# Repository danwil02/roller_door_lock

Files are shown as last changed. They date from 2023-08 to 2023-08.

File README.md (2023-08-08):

# Roller Door Lock

Simple project to control a 3D printed locking mechanism for a garage roller door.

The final setup allows me to lock and unlock my old and un-motorised garage door remotely via HomeKit.

## Setup

Create a copy of `conf.json` called `conf.local.json`. Fill in your Wifi and MQTT broker details.

## Dependancies
- I used [mosquitto broker](https://mosquitto.org/) in this project.
- For homekit integration install [homebridge](https://homebridge.io/how-to-install-homebridge) and the [homebridge-mqtt](https://github.com/cflurin/homebridge-mqtt#readme) plugin.

## Hardware

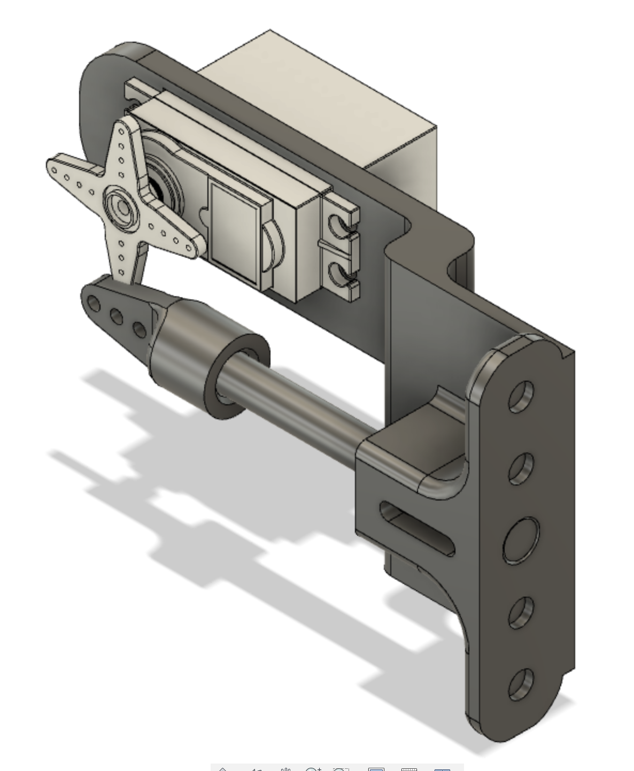
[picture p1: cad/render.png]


### 3D Printing
The following items were printed in PLA 0.4mm nozzle on a Prusa i3 mk3:
- `cad/bolt guide v3.stl`
- `cad/bolt control horn v1.stl`

### Assembly Notes
The bolt was a shortened 8mm OD smooth steel rod from an old Prusa printer left over from a previous upgrade. NOTE: Make sure to measure your setup to get an appropriate length.

The control horn attaches to the rod using glue and the horn attaches to the servo using chicken wire.

Finally, the assembly attaches to my garage door using two sheet metal screws.

For detailed informaiton see `cad/garage door lock assembly v4.step`.

### Essential Electronics
- Raspberry Pi Pico W with Soldered Male Headers
- Raspberry Pi 4 Power Supply (Official) - USB-C 5.1V 15.3W (White)	1
- PiicoDev Precision Temperature Sensor TMP117
- PiicoDev Cable 50mm	x4
- PiicoDev Cable 100mm	x5
- PiicoDev OLED Display Module (128x64) SSD1306
- PiicoDev Buzzer Module
- PiicoDev Expansion Board for Pico (Non-Recharging)
- PiicoDev Servo Driver (4 Channel)

### Optional Electronics
Could be used to extend the project in the future.
- USB Cable Type A to Micro B (1m)	x4
- Heat Shrink Kit
- 16mm Illuminated Pushbutton - Red Latching On/Off Switch	x2
- Resistor 330 Ohm 1/4 Watt PTH - 20 pack (Thick Leads)	1

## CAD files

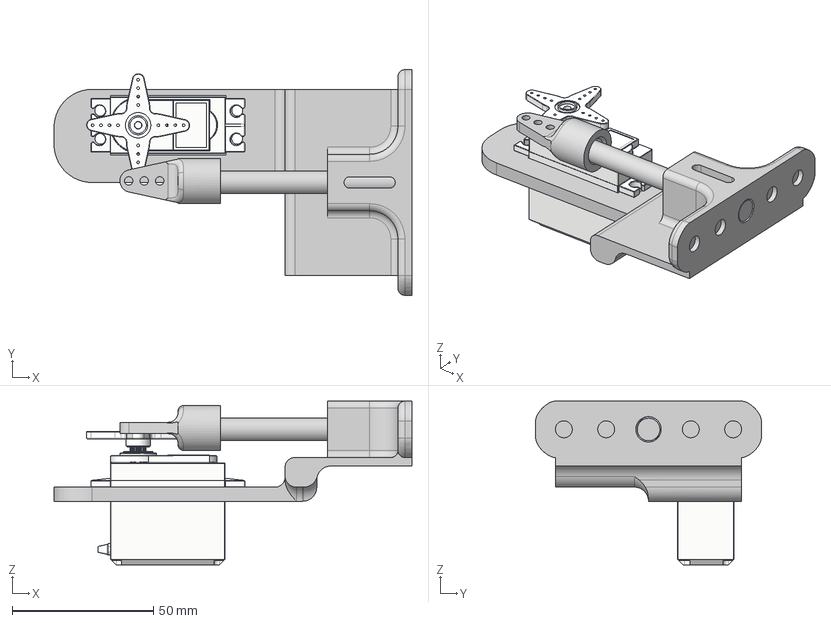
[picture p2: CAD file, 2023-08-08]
cad/garage door lock assembly v4.step
126.9 x 80.0 x 58.1 mm
bolt
bolt control horn
Aspa-creu-Axix holder v2
bolt guide

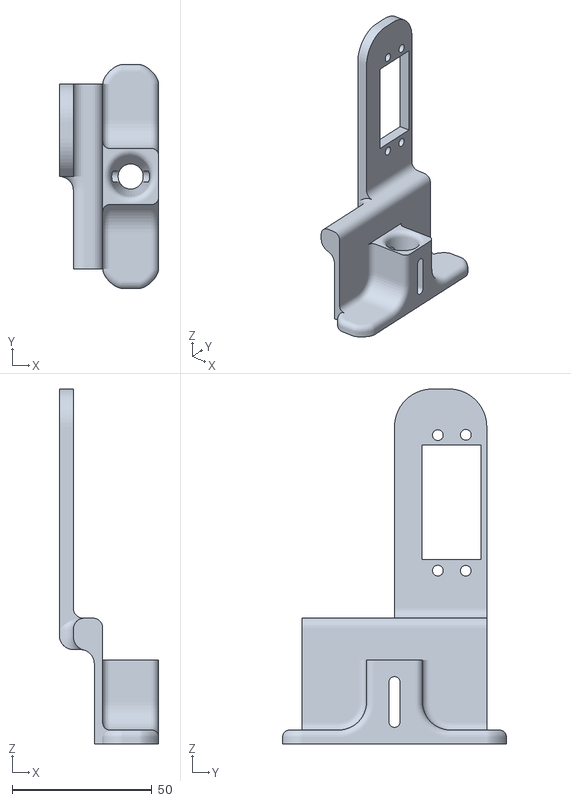
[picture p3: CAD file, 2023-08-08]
cad/bolt guide v3.stl
35.5 x 80.0 x 126.9

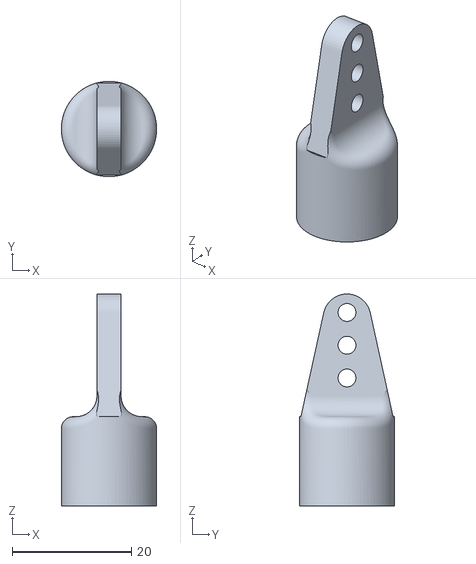
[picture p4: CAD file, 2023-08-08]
cad/bolt control horn v1.stl
16.0 x 16.0 x 35.6

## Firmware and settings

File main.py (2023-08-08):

from mqtt import Mqtt
from servo import Servo
from buzzer import Buzzer
from log_manager import get_logger, get_stack_trace
from PiicoDev_TMP117 import PiicoDev_TMP117, sleep_ms
from led import flash_led
import json
from wifi import Wifi
from buzzer import Buzzer
from display import Display
from machine import WDT

watchdog = WDT()

logger = get_logger(__name__)


def run():
    tempsensor = PiicoDev_TMP117()
    buzzer = Buzzer()
    servo = Servo()
    disp = Display()
    tempC = 0

    flash_led()

    logger.info("Start Setup")

    with open("conf.local.json", "r") as f:
        json_str = " ".join(f.readlines())
    conf = json.loads(json_str)

    device_name = conf["Name"]
    wifi = Wifi(conf["SSID"], conf["Password"], buzzer)
    disp.display_setup_state("WIFI connecting")
    wifi.connect(display=disp, watchdog=watchdog)
    mqtt_client = Mqtt(
        conf["MQTT"]["Host"], wifi, conf["MQTT"]["User"], conf["MQTT"]["Password"]
    )

    disp.display_setup_state("MQTT connecting")
    mqtt_client.connect()
    watchdog.feed()
    mac = wifi.get_mac()
    garage_door_lock_name = mac + "_garage_door_lock"

    def sub_callback(topic, message):
        json_response = json.loads(message)
        logger.debug(f"Subscribe {topic}, {json_response}")
        if topic == b"homebridge/from/set":
            logger.debug("Handle homebridge/from/set")
            if json_response["name"] == garage_door_lock_name:
                logger.info(f"Set servo to {json_response['value']}")
                servo.set(json_response["value"])
                disp.update_display(tempC, servo.locked)
                buzzer.play_success_melody()

    flash_led(2)
    disp.display_setup_state("MQTT setup")

    mqtt_client.set_sub_callback(sub_callback)
    mqtt_client.sub("homebridge/from/response")
    mqtt_client.sub("homebridge/from/set")
    mqtt_client.pub("homebridge/to/get", json.dumps({"name": "*"}))
    mqtt_client.pub(
        "homebridge/to/add",
        json.dumps(
            {
                "name": mac + "_temperature",
                "service_name": "temperature",
                "service": "TemperatureSensor",
            }
        ),
    )
    mqtt_client.check_msg()
    mqtt_client.pub(
        "homebridge/to/add",
        json.dumps(
            {
                "name": garage_door_lock_name,
                "service_name": "switch",
                "service": "Switch",
            }
        ),
    )
    mqtt_client.check_msg()

    logger.info("Running")
    disp.display_setup_state("Running...")
    while True:
        flash_led(1)
        logger.debug("read temperature")
        tempC = tempsensor.readTempC()
        # sensors/<measurement>/<mac>/<device_name>
        topic = f"sensors/temperature/{mac}/{device_name}"
        msg = str(tempC)

        mqtt_client.pub(topic, msg)

        mqtt_client.pub(
            "homebridge/to/set",
            json.dumps(
                {
                    "name": mac + "_temperature",
                    "service_name": "temperature",
                    "characteristic": "CurrentTemperature",
                    "value": tempC,
                }
            ),
        )
        disp.update_display(tempC, servo.locked)

        # Wait 10 seconds before next temp reading
        for i in range(0, 1000):
            mqtt_client.check_msg()
            sleep_ms(10)
            watchdog.feed()


def disp_err(msg):
    try:
        disp = Display()
        disp.display.fill(0)
        disp.display.text("Error", 0, 0, 1)  # literal string
        disp.display.text(msg, 0, 15, 1)  # string variable
        disp.display.show()

        buzzer = Buzzer()
        buzzer.play_fail_melody()
    except Exception as e:
        logger.error(str(e))
        logger.error(get_stack_trace(e))


if __name__ == "__main__":
    while True:
        try:
            run()
        except Exception as e:
            logger.error(str(e))
            logger.error(get_stack_trace(e))
            disp_err(str(e))
            # panic(e)
        # finally:
        #     logger.info("Exiting program")
        logger.info("Sleeping")
        sleep_ms(500)

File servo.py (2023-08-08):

from PiicoDev_Servo import PiicoDev_Servo, PiicoDev_Servo_Driver, sleep_ms

ENGAGED_DEG = 140
RETRACTED_DEG = 10
MIDDLE_ISH_DEG = 90

class Servo:
    def __init__(self, channel=1) -> None:
        # Initialise the Servo Driver Module
        controller = PiicoDev_Servo_Driver()
        # Simple setup: Attach a servo to channel 1 of the controller with default properties
        self.servo = PiicoDev_Servo(controller, channel)
        self.locked = None

    def toggle(self):
        if self.servo.angle < MIDDLE_ISH_DEG:
            self.servo.angle = ENGAGED_DEG
        else:
            self.servo.angle = RETRACTED_DEG

    def set(self, engage):
        if engage:
            self.servo.angle = ENGAGED_DEG
            self.locked = True
        else:
            self.servo.angle = RETRACTED_DEG
            self.locked = False

    def test(self):
        # Step the servo
        self.servo.angle = RETRACTED_DEG
        sleep_ms(1000)
        self.servo.angle = ENGAGED_DEG
        sleep_ms(5000)
        self.servo.angle = MIDDLE_ISH_DEG

def servo_test():
    print("Servo test . . . ")
    servo = Servo()
    servo.test()
    servo.set(True)
    sleep_ms(1000)
    servo.set(False)
    print("Servo test . . . Done")

if __name__ == "__main__":
    servo_test()
